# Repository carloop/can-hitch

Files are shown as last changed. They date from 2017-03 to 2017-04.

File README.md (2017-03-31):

# CAN Hitch
## _A CAN Bus Transceiver Breakout_

Connect microcontrollers together with CAN bus.

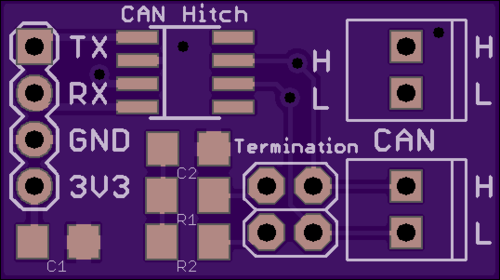
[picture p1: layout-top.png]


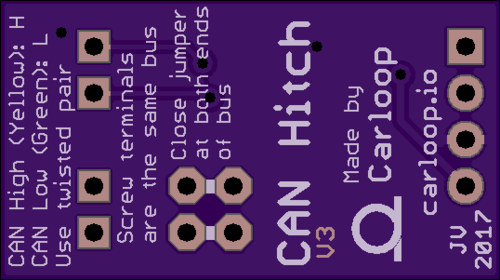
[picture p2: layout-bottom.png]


- [Schematics](CAN-breakout-3.3V-v3.pdf)
- [Bill of materials](CAN-breakout-3.3V-v3_BOM.csv)

## License

Copyright 2017 Carloop
Released under the MIT license

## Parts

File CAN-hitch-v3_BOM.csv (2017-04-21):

Qty-1 | Part References | Value | Package | Mfg Part Num | Mfg Name | VID | Vendor Part Num | Description | XREF
2 | JP3, JP4 |  | 1X02_2.54_SCREWTERM | OSTVN02A150 | On Shore Technology Inc. | DK | ED10561-ND | CONN TERM BLOCK 2.54MM 2POS PCB | REF60
1 | JP2 |  | 2X2 | PREC002DAAN-RC | Sullins Connector Solutions | DK | S2012EC-02-ND | CONN HEADER .100in DUAL STR 4POS | REF66
1 | JP1 |  | 1X04 | PREC004SAAN-RC | Sullins Connector Solutions | DK | S1012EC-04-ND | CONN HEADER .100in SNGL STR 4POS | REF65
1 | C1 | 0.1u | C1206 | 12065C104KAT2A | AVX | DK | 478-1556-1-ND | CERAMIC CAPACITORåÊ0.1UF 50V X7R 10%åÊ1206 | REF61
1 | C2 | 0.01u | C1206 | 12065C103KAT2A | AVX | DK | 478-1542-1-ND | MLCC CAPACITORåÊ0.01uF 50V X7R 10%åÊ1206 FULL REEL | REF62
2 | R1, R2 | 62 | R1206 | RC1206FR-0762RL | Yageo | DK | 311-62.0FRCT-ND | RES SMD 62 OHM 1% 1/4W 1206 | REF63
1 | JP1-ALT | BOM-ENTRY | * | PEC04SBBN | Sullins Connector Solutions | DK | S1122E-04-ND | CONN HEADER .100in SINGL R/A 4POS | REF67
1 | IC1 | SN65HVD232 | SO8 | SN65HVD232DR | Texas Instruments | DK | 296-26344-1-ND | IC CAN TRANSCEIVER 3.3V 8-SOIC | REF64
1 | Jumper |  | * | MNT-102-BK-G | Samtec | DK | SAM9042-ND | CONN SHUNT 4POS | *

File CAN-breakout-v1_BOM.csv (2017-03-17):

Qty-1 | Part References | Value | Package | Mfg Part Num | Mfg Name | VID | Vendor Part Num | Description | XREF
2 | JP3, JP4 |  | 1X02_2.54_SCREWTERM | OSTVN02A150 | On Shore Technology Inc. | DK | ED10561-ND | CONN TERM BLOCK 2.54MM 2POS PCB | REF60
1 | JP2 |  | 1X02 | PREC002SAAN-RC | Sullins Connector Solutions | DK | S1012EC-02-ND | CONN HEADER .100"" SNGL STR 2POS | REF59
1 | JP1 |  | 1X05 | PREC005SAAN-RC | Sullins Connector Solutions | DK | S1012EC-05-ND | CONN HEADER .100"" SNGL STR 5POS | REF58
2 | C1, C2 | 0.1u | C1206 | GRM155R71C104KA88D | Murata | DK | 490-3261-1-ND | 0.10µF ±10% 16V X7R Ceramic Capacitor -55°C ~ 125°C Surface Mount MLCC 0402 | REF48
1 | R2 | 60 | R1206 | ERJ-2RKF1002X | Panasonic Electronic Components | DK | P10.0KLCT-ND | RES SMD 10K OHM 1% 1/10W 0402 | REF50
1 | R1 | 60 | R1206 | ERJ-2RKF6202X | Panasonic Electronic Components | DK | P62.0KLCT-ND | RES SMD 62K OHM 1% 1/10W 0402 | REF49
1 | IC1 | TJA1049 | SO8 | TJA1049T-118 | NXP Semiconductors | DK | 568-8682-1-ND | IC CAN TRANSEIVER HS 8SOIC | REF16

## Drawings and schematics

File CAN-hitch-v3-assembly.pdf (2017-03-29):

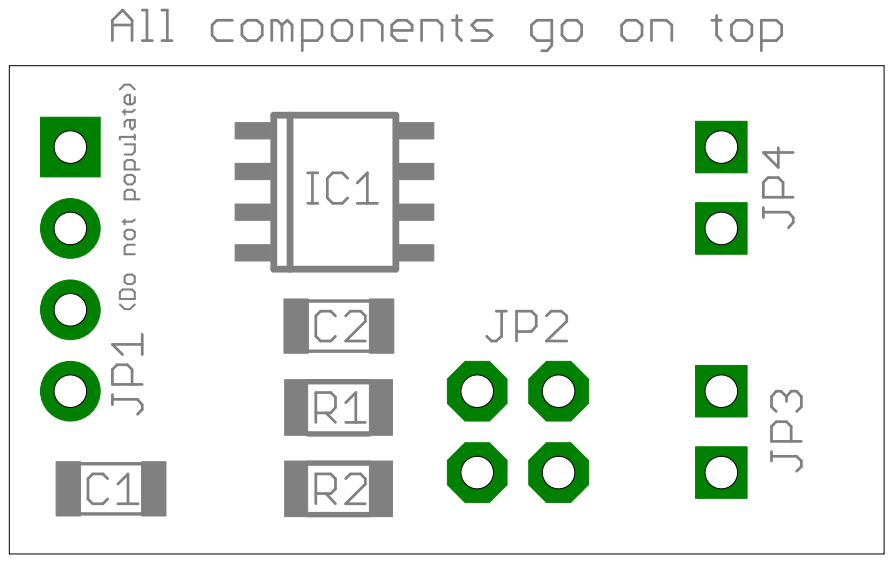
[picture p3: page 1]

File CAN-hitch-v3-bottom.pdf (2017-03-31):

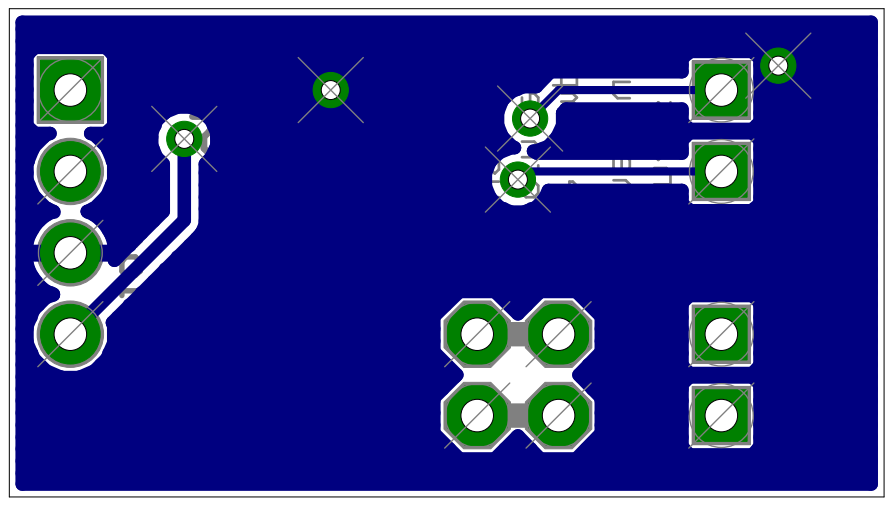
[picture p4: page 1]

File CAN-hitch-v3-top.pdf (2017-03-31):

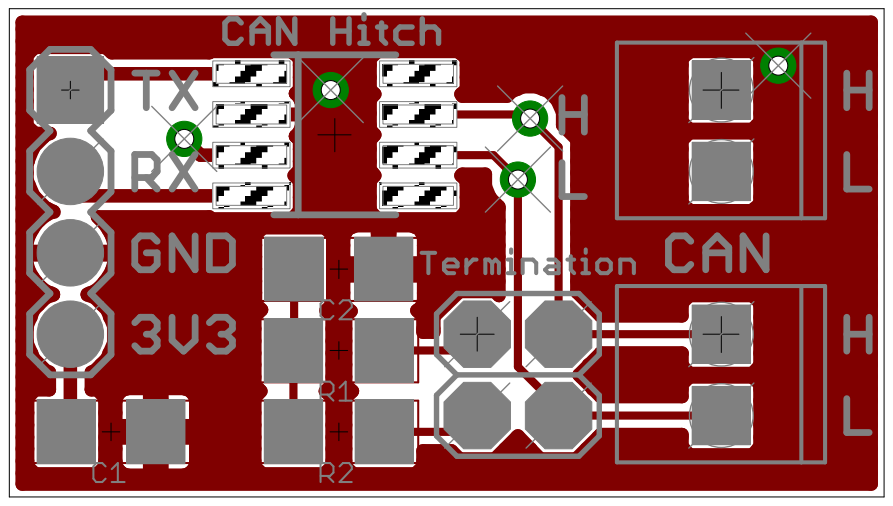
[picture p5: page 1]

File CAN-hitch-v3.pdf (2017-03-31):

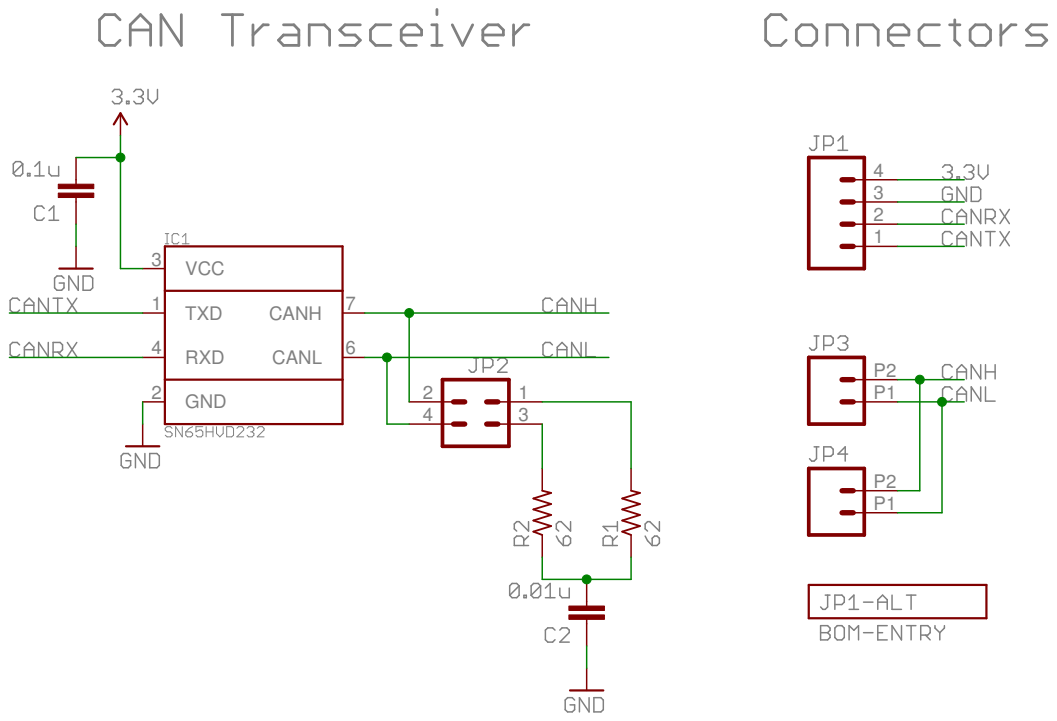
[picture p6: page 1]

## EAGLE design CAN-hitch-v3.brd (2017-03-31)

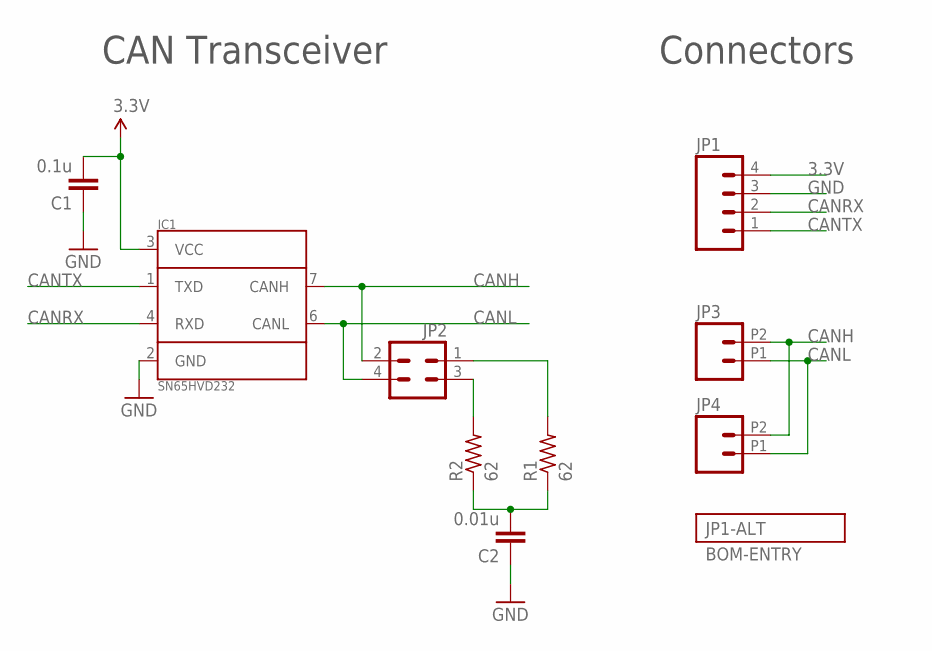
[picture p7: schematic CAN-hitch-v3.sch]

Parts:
C1: 0.1u; C1206; PARTNO 12065C104KAT2A
C2: 0.01u; C1206; PARTNO 12065C103KAT2A
IC1: SN65HVD232; SO8; PARTNO SN65HVD232DR
JP1: M04PTH; 1X04; PARTNO PREC004SAAN-RC
JP2: M02X2; 2X2; PARTNO PREC002DAAN-RC
JP3, JP4: M022.54MM_SCREWTERM; 1X02_2.54_SCREWTERM; PARTNO OSTVN02A150
R1, R2: 62; R1206; PARTNO RC1206FR-0762RL

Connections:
3.3V: C1.2, IC1.3 (VCC), JP1.4
CANH: IC1.7 (CANH), JP2.2, JP3.P2 (2), JP4.P2 (2)
CANL: IC1.6 (CANL), JP2.4, JP3.P1 (1), JP4.P1 (1)
CANRX: IC1.4 (RXD), JP1.2
CANTX: IC1.1 (TXD), JP1.1
GND: C1.1, C2.1, IC1.2 (GND), JP1.3
unnamed: JP2.1, R1.2
unnamed: C2.2, R1.1, R2.1
unnamed: JP2.3, R2.2

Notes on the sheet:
CAN Transceiver
Connectors

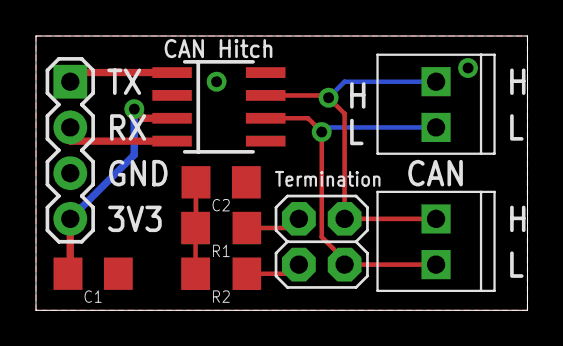
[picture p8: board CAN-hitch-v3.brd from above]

Board: 2 copper layers, 27.3 x 15.2 mm, 9 parts (0 on the bottom side), 9 nets.

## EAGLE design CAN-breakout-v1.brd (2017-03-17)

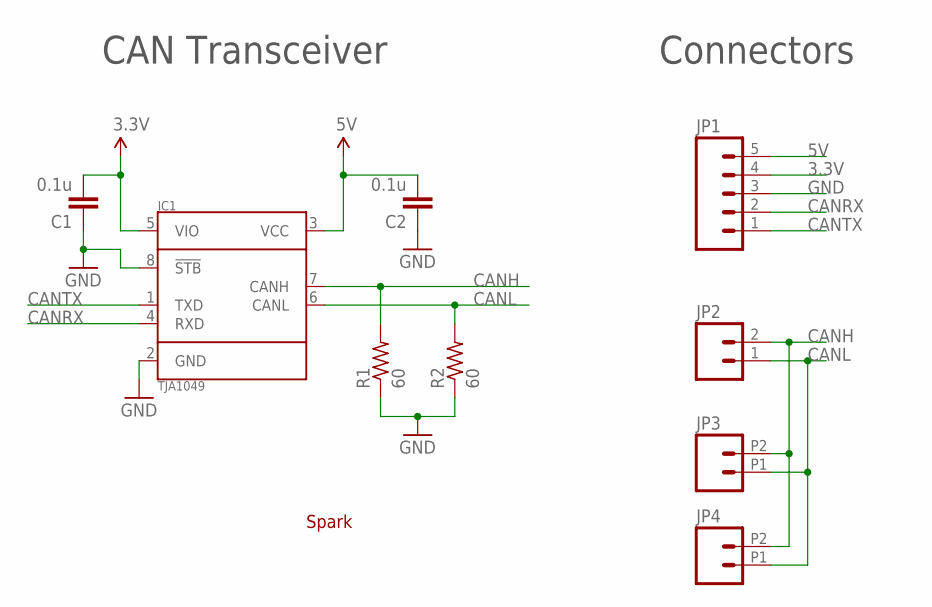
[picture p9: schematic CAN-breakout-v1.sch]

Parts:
C1, C2: 0.1u; C1206; PARTNO GRM155R71C104KA88D
IC1: TJA1049; SO8; PARTNO TJA1049T-118
JP1: M05PTH; 1X05; PARTNO PREC005SAAN-RC
JP2: M02PTH; 1X02; PARTNO PREC002SAAN-RC
JP3, JP4: M022.54MM_SCREWTERM; 1X02_2.54_SCREWTERM; PARTNO OSTVN02A150
R1: 60; R1206; PARTNO ERJ-2RKF6202X
R2: 60; R1206; PARTNO ERJ-2RKF1002X
U$3: SPARK_LOGO2

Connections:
3.3V: C1.2, IC1.5 (VIO), JP1.4
5V: C2.2, IC1.3 (VCC), JP1.5
CANH: IC1.7 (CANH), JP2.2, JP3.P2 (2), JP4.P2 (2), R1.2
CANL: IC1.6 (CANL), JP2.1, JP3.P1 (1), JP4.P1 (1), R2.2
CANRX: IC1.4 (RXD), JP1.2
CANTX: IC1.1 (TXD), JP1.1
GND: C1.1, C2.1, IC1.2 (GND), IC1.8 (!STB), JP1.3, R1.1, R2.1

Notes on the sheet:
CAN Transceiver
Connectors

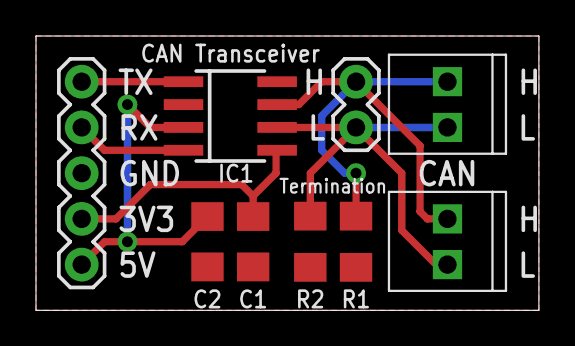
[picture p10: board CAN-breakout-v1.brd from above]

Board: 2 copper layers, 27.9 x 15.2 mm, 10 parts (1 on the bottom side), 7 nets.

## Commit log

2017-03-17 First version sent to OSH Park
    [CAN-breakout-v1.brd, CAN-breakout-v1.sch, CAN-breakout-v1_BOM.csv]
2017-03-17 Fix the termination
    [CAN-breakout-v2.brd, CAN-breakout-v2.sch, CAN-breakout-v2_BOM.csv]
2017-03-17 quote csv properly
    [CAN-breakout-v2_BOM.csv]
2017-03-27 Add 3.3V variant
    [CAN-breakout-3.3V-v3.brd, CAN-breakout-3.3V-v3.sch]
2017-03-29 Create Gerbers
    [CAN-breakout-3.3V-v3.GBL, CAN-breakout-3.3V-v3.GBO, CAN-breakout-3.3V-v3.GBS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]
2017-03-31 Update layout files
    [CAN-breakout-v2.brd, CAN-breakout-v2.sch, CAN-breakout-v2_BOM.csv]
2017-03-31 Rename project
    [CAN-breakout-3.3V-v3.GBS, CAN-hitch-v3.GBL, CAN-hitch-v3.GBO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]
2017-04-21 Added jumper to CAN-hitch-v3_BOM.csv
    [CAN-hitch-v3_BOM.csv]

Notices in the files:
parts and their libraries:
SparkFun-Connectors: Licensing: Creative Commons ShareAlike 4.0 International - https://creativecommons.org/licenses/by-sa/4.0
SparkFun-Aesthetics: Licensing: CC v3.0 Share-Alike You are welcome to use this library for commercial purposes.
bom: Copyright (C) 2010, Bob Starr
